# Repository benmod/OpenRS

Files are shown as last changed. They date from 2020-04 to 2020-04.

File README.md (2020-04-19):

# OpenRS - Open Respiratory Sensor

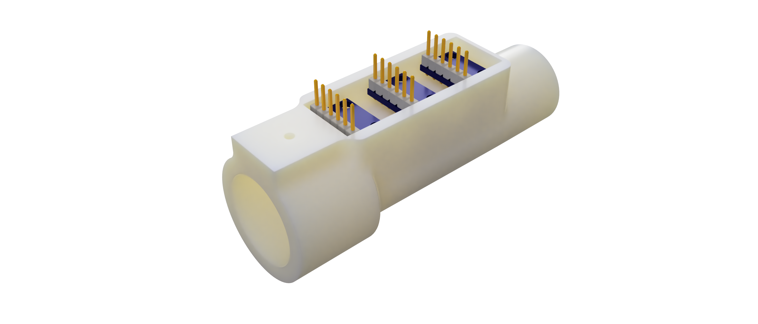
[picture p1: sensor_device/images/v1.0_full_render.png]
Venturi-flow sensor unit, v1.0


**Disclaimer:** This project is not meant to be used as a medical device as it is. It has not been reviewed nor validated by any trained professional and should not be used with any patients. In its current state it is only meant to demonstrate what is achievable with a very low resource design and provide inspiration for other projects. 

## Project Summary

This projects ultimate aim is to offer an open-source, affordable, and easy to make respiratory sensor design. The primary focus of this sensor is to be used with a feedback device to assist in the safe operation of a manual ventilation device (bag valve mask). It is however not limited to that use and could also be used as part of a mechanical ventilator. 

The project is composed of the sensor device itself as well as of a ventilation feedback device (VFD) that uses the sensor readings to provide visual and auditory feedback to the bag valve mask operator.

## Context and use case

Many developing countries have a critical lack of mechanical ventilator, with at least 10 countries in Africa having none at all and 9 other having less than 1 per million people [[1](https://www.nytimes.com/2020/04/18/world/africa/africa-coronavirus-ventilators.html)]. In that context, practicians are often forced to use manual ventilation with bag valve masks (BVM) in lieu of mechanical ventilation. However, such manual ventilation requires around-the-clock operation and the lack of trained practician in those settings often mean that the family members of the patients are asked to operate the manual ventilators themselves for extended periods of time [[2](https://academic.oup.com/qjmed/article/101/12/990/1564042)]. This present serious risks as improper use of BVMs can cause very serious lung injuries that can cause long term disability and even death [[3](https://www.ncbi.nlm.nih.gov/pubmed/8637092)],[[4](https://www.ncbi.nlm.nih.gov/pubmed/3280263)]. Several studies have found that even amongst trained professionals improper use of BVM was endemic [[5](https://www.ncbi.nlm.nih.gov/pubmed/15066941)] with one study finding that over 88% of practicians evaluated delivered excessive pressure and 73% delivered excessive volume [[6](https://www.ncbi.nlm.nih.gov/pubmed/22005778)]. To remedy this issue, devices providing feedback on manual ventilation have already been shown to decrease the risk of misuse by >70% [[6](https://www.ncbi.nlm.nih.gov/pubmed/22005778)]. However, the current designs are not open source, too complex to replicate and too expensive for use in low resource settings. Our proposed open source design is optimized for affordability and ease of replication to fill that current gap. 

## Sensor device

The sensor device provides measurement of airway pressure and gas flow (bi-directional). It is designed to be placed close to the patient and measure those metrics with a meaningful range and accuracy for respiratory monitoring. 

**Documentation:**   
- [Requirements](sensor_device/sensor_device_requirements.md)  
- Design specifications  
- Tests (TODO)  

**Design Files:**   
- The *CAD* folder for the Fusion 360 archive including the full assembly.  
- The *source* folder includes an Arduino project with the source code to read the sensor  

**Manufacturing Files:**  
- The *CAM* folder includes an STL file for 3D printing  
- The *assembly_manual* file includes instruction on how to 3D print the part and assemble them. 

## Ventilation Feedback Device (VFD)

The main aim of the ventilation feedback device is to provide feedback to someone manually operating a bag valve mask in order to ensure safe usage and reduce the risk of lung damage from improper use. 

**Documentation:** (TODO)

## Project Progress

### Current Status
A first version of the sensor device has been designed and manufactured. First tests have started and early results are promising but more work is needed to properly assess the performance of the sensor. 

### Next Steps
The most critical next task is to properly test and qualify the sensor. This involve validating the design as well as defining protocols to easily test manufactured units in a low resource environment. Creative solutions will be needed and any help is highly appreciated. 

Moreover, during manufacturing and early tests of the sensor, a few areas for improvements have been identified, in particular:   
- Firmware: Add temperature compensation of the fluid density  
- Firmware: Add noise filtering  
- Mechanical: Add additional pressure leakage protection close to the sensors  

Once this is done, the proper design of the Ventilation Feedback Device can be started.

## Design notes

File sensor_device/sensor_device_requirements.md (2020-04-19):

# Requirements  
  
Those requirements are based on the analysis of different commercially available sensors as well as medical literature around ventilation. We made an effort to distinguish between what would be an ideal and what would be still acceptable for the use case. 
  
## Key Requirements  
 
 - Proximal Flow measurement
 - Proximal Pressure measurement
 - Compatibility with standard connectors used in BVMs and ventilators (see **[ISO 5356-1:2015](https://www.iso.org/standard/54851.html?browse=tc)**)
 - Affordability (manufacturing cost <10$)
 - Ease of manufacturing (only 3D printing and common parts)

## Functional Parameters

|Parameter|Minimum Viable Value|Ideal Value|
|--|--|--|
| Pressure Range | 0 - 2 kPa (0 - 20 cmH2O) | -4 - +4 kPa (-42 - +41 cmH2O) | 
| Pressure Resolution | 0.2 kPa (2 cmH2O) | 0.1 kPa (1 cmH2O) |
| Pressure Accuracy | <10% m.v | <5% m.v |
| Pressure Noise Level | <5% m.v | <2.5% m.v |
| Pressure Update Time | <100 ms | <10 ms |
| Flow Range | 0 - 100 slm | -250 - +250 slm |
| Flow Resolution | 1 slm | 0.2 slm |
| Flow Offset | 2 slm | 0.2 slm |
| Flow Accuracy | <20% m.v | <5% m.v |
| Flow Noise Level | <5% m.v | <2.5% m.v |
| Flow Update Time | <100 ms | <10 ms |
| Pressure drop | <1 kPa (10 cmH2O) | <0.5 kPa (5 cmH2O) |
| Dead Space | <25 mL | <10 mL |

**m.v:** measured value  
**slm:** standard liter per minute

## Operating Parameters
|Parameter|Minimum Viable Value|Ideal Value|
|--|--|--|
| Operating Temperature | +5 - +35 °C | 0 - +50 °C |
| Operating Humidity (relative) | 10 - 95 % (non-condensing) | 10 - 95 % (non-condensing) |
| Media Compatibility | Air, N2, O2 | Air, N2, O2, other non- aggressive gases |

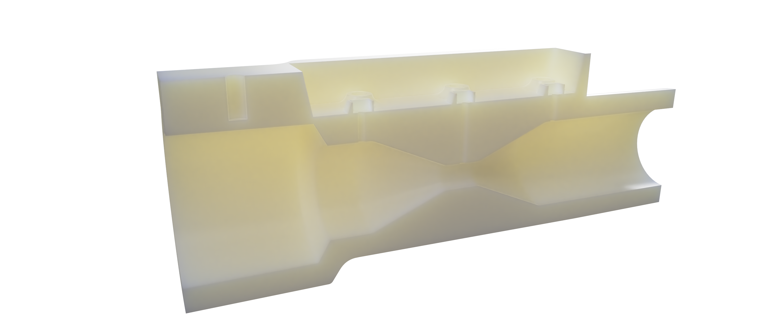
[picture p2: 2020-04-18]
sensor_device/images/v1.0_section_render.png

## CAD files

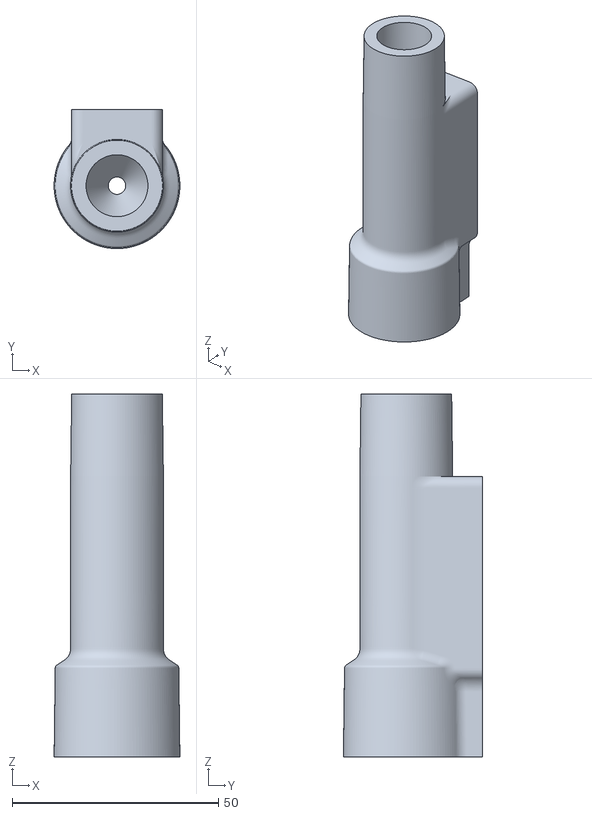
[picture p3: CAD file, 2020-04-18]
sensor_device/CAM/venturi_based_sensor_v1.0_body.stl
30.5 x 33.7 x 88.0

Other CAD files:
sensor_device/CAD/venturi_based_sensor_v1.0.f3z

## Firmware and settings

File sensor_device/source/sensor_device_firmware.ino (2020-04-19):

#include <SPI.h>
#include <Adafruit_Sensor.h>
#include <Adafruit_BMP280.h>

#define BMP_SCL 13
#define BMP_SDO 12
#define BMP_SDA 11

#define BMP_CSB1 10
#define BMP_CSB2 9
#define BMP_CSB3 8
#define BMP_CSB4 7

// This was pre-computed as (tube_area / sqrt((tube_area / neck_area) ** 2 - 1)) * discharge_coefficient * 1000
#define VENTURI_PARAMETER 0.013619255 
// This should be temperature compensated in a future version
#define FLUID_DENSITY 1.29 


// Proximal pressure sensor
Adafruit_BMP280 bmp1(BMP_CSB1, BMP_SDA, BMP_SDO, BMP_SCL);

// Venturi neck pressure sensor
Adafruit_BMP280 bmp2(BMP_CSB2, BMP_SDA, BMP_SDO, BMP_SCL);

// Distal pressure sensor
Adafruit_BMP280 bmp3(BMP_CSB3, BMP_SDA, BMP_SDO, BMP_SCL);

// Ambient pressure sensor
Adafruit_BMP280 bmp4(BMP_CSB4, BMP_SDA, BMP_SDO, BMP_SCL);


float calculate_flowrate(float p1, float p2, float p3) {
  float delta_p = 0;
  bool negative = false;
  if(p1 - p2 > p3 - p2) {
    delta_p = p1 - p2;
  } else {
    delta_p = p3 - p2;
    negative = true;
  }
  if(delta_p > 0) {
    float flowrate = (sqrt((2.0*delta_p)/FLUID_DENSITY) * VENTURI_PARAMETER);
    if(negative) {
      return -flowrate;
    } else {
      return flowrate;
    }
  } else {
    return 0.0;
  }
}


void setup() {
  Serial.begin(9600);
  Serial.println("Started setup...");

  // We init the sensors
  Serial.println("Starting BMP280 device 1...");
  if (!bmp1.begin()) {
    Serial.println("BMP280 device 1 was not found.");
    while (1);
  }
  Serial.println("BMP280 1 started.");

  Serial.println("Starting BMP280 device 2...");
  if (!bmp2.begin()) {
    Serial.println("BMP280 device 2 was not found.");
    while (1);
  }
  Serial.println("BMP280 2 started.");

  Serial.println("Starting BMP280 device 3...");
  if (!bmp3.begin()) {
    Serial.println("BMP280 device 3 was not found.");
    while (1);
  }
  Serial.println("BMP280 3 started.");

  Serial.println("Starting BMP280 device 4...");
  if (!bmp3.begin()) {
    Serial.println("BMP280 device 4 was not found.");
    while (1);
  }
  Serial.println("BMP280 4 started.");
  Serial.println("Finished setup...");
}

void loop() {
  float ambient = bmp4.readPressure();
  float p1 = bmp1.readPressure();
  float p2 = bmp2.readPressure();
  float p3 = bmp3.readPressure();
  float flowrate = calculate_flowrate(p1, p2, p3);
  Serial.print(flowrate*60.0);
  Serial.print(" slm\n");
  float proximal_pressure = p1 - ambient;
  // We convert to hPa for ease of reading in the Arduino Plotter
  Serial.print(proximal_pressure/100.0);
  Serial.print(" hPa\n");
  delay(10);
}

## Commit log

2020-04-18 First proper commit: basic project description and mechanical CAD and CAM files.
    [venturi_based_sensor_v1.0.f3z, venturi_based_sensor_v1.0_body.stl]
2020-04-19 Updated documentation.
    [venturi_based_sensor_v1.0.f3z, venturi_based_sensor_v1.0_body.stl]
2020-04-19 Added first version of the Arduino code.
